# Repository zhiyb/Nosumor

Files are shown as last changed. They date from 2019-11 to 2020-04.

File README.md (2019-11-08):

# USB Mix

Design a small USB keyboard for playing [osu!](https://osu.ppy.sh/): [Blog posts](https://zhiyb.wordpress.com/category/cc/embedded/nosumor/)

In addition to mandatory keyboard functionalities, USB audio and Micro SD support are also added. So it's now called USB Mix.

The PCB layout was made compatible with [the original Nosumor v3 casing](http://noodlefighter.com/工作日志/log_nono/), which sells on [the official osu! store](https://osu.ppy.sh/store/product/20).

However, as a hobby project for learning USB framework and achieving high performance, the parts used in this design are probably unnecessarily expensive.

## Features

- USB 2.0 high-speed connection with 8kHz polling rate
- 5 switches (2x Cherry MX switches & 3x tactile switches)
- RGB lighting!
- Audio output through headphone jack using USB audio class 2
- Micro SD card reader
- Application for dynamic reconfiguration and firmware upgrade

### Planned features

- Audio input (MIC) through headphone jack
- MPU-9250 9-axis motion sensor
- ADC waveform capture
- DAC waveform generation

## PCB features

- 50×50 (mm) board area
- 2 mechanical keyboard switches (Cherry MX RGB compatible) and 3 tactile buttons
- Keycap and bottom-side RGB lighting
- STM32F722RE Cortex-M7 high performance MCU @216MHz
- USB 2.0 high-speed PHY USB3370
- 3.5mm audio jack with TLV320AIC3110 audio codec
- InvenSense MPU-9250 9-axis motion sensor
- On-board FT2232D connected to UART & JTAG for debugging
- Test points for 2xADC & 1xDAC
- Extension UART port with 3.3V power

Gerber files for PCB manufacturer Seeed Studio provided.

## Estimated costs

Configuration | Cost
---|---
Basic keyboard | £20
With audio and Micro SD slot | £30
Also with debugging USB port | £38

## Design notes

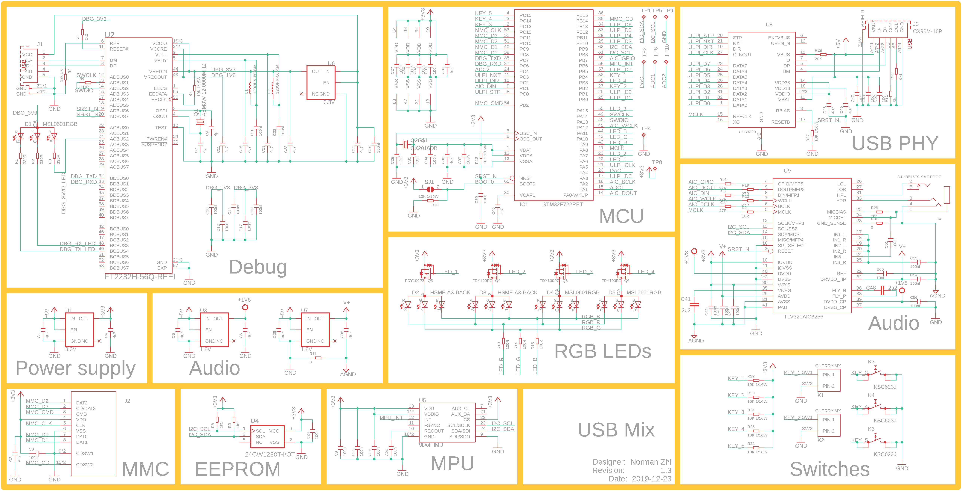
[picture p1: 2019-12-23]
images/schematic.png

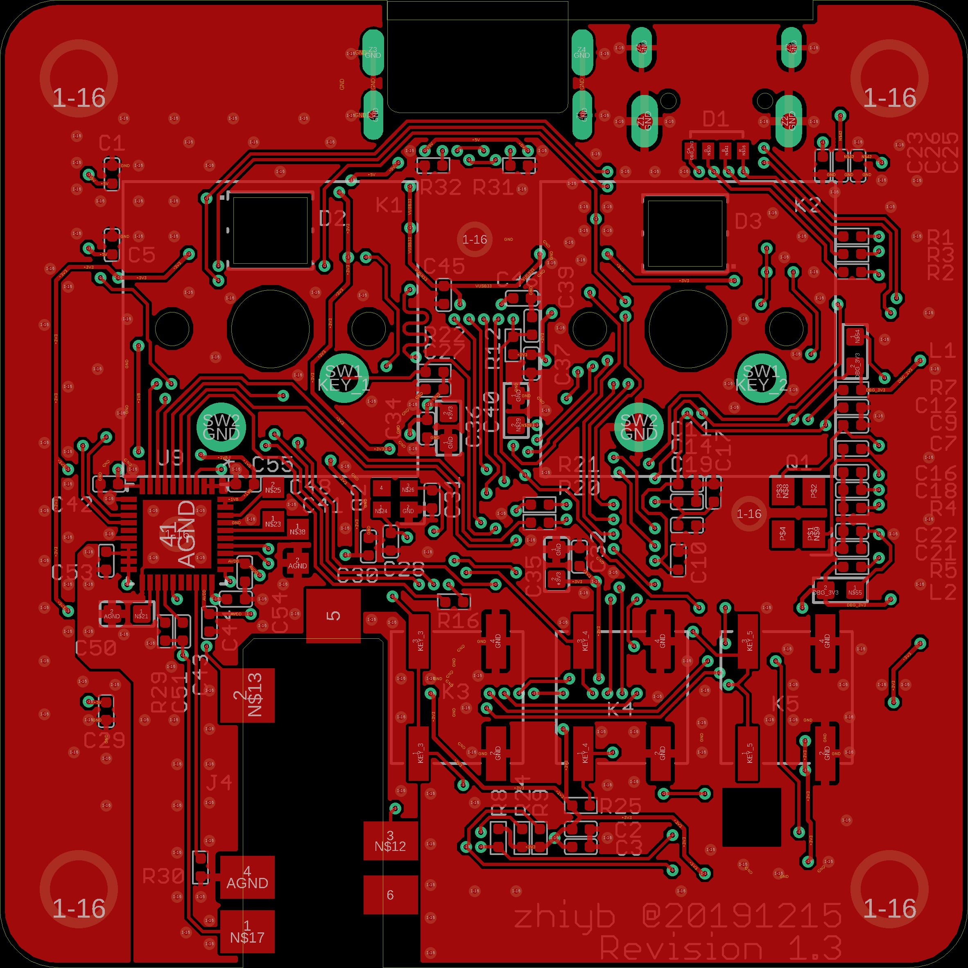
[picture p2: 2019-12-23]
images/top.png

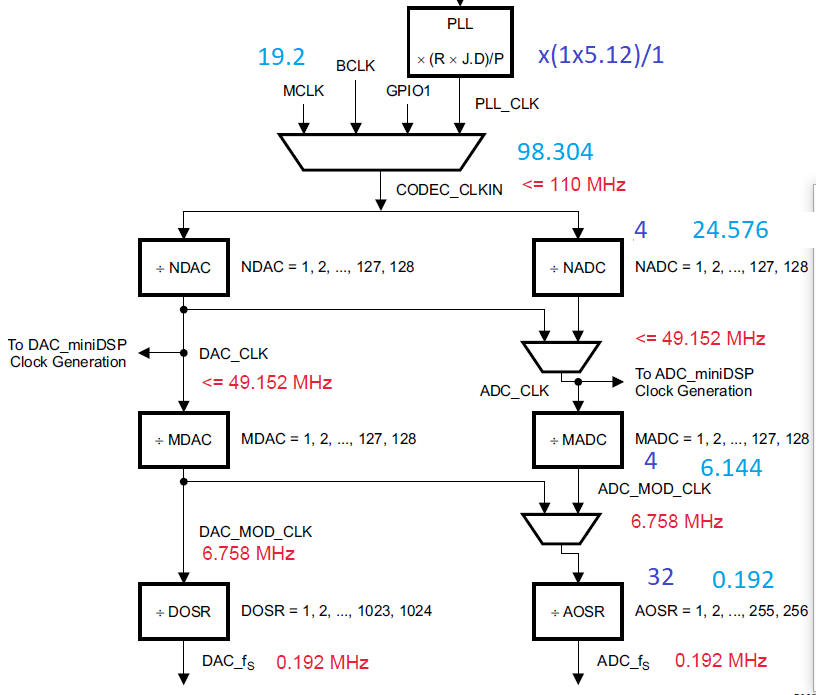
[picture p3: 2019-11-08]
images/codec.png

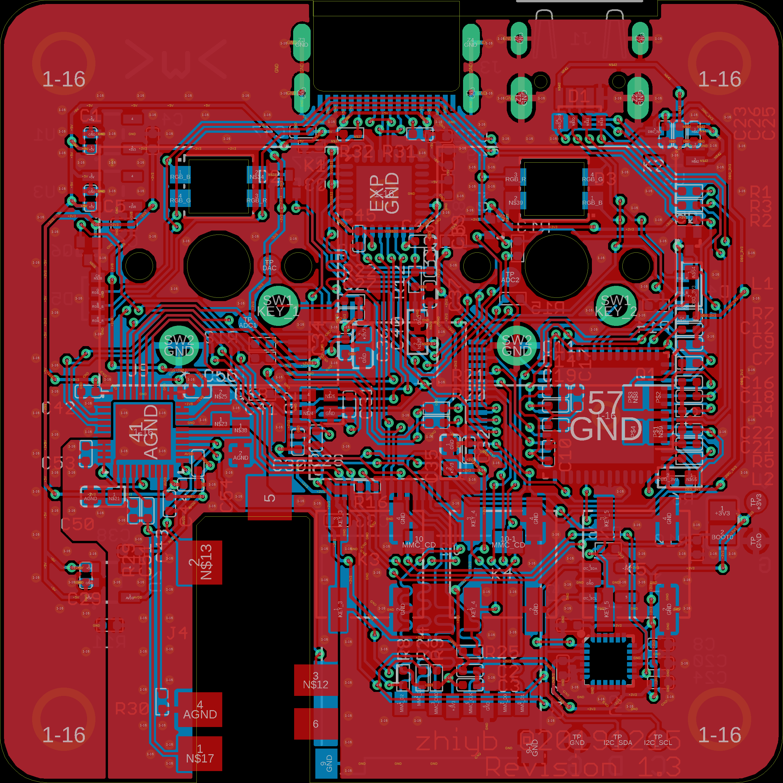
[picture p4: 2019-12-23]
images/both.png

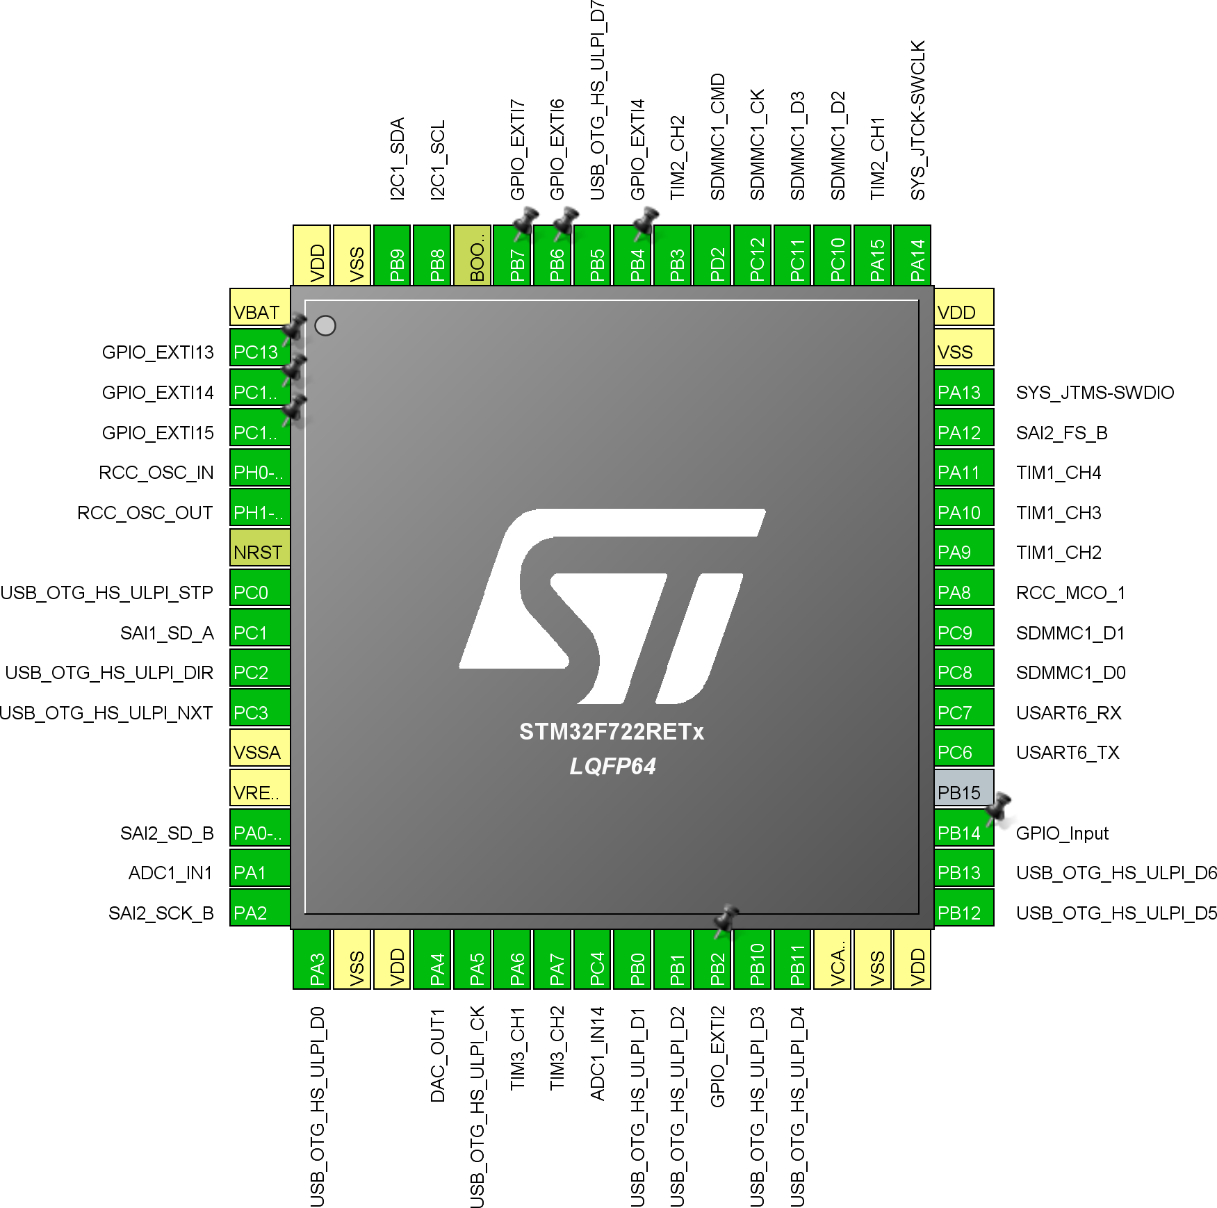
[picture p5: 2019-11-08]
images/chip.png

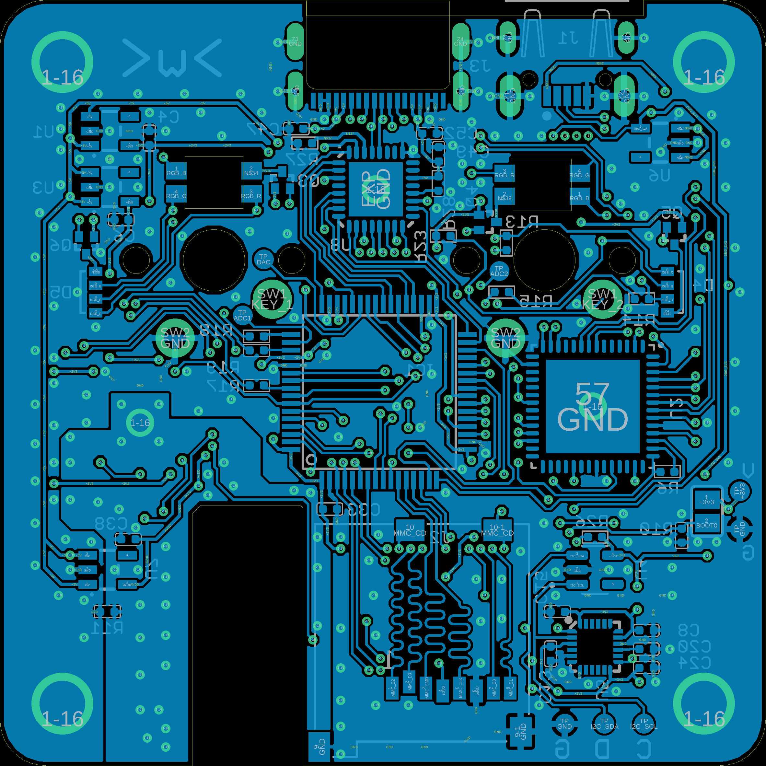
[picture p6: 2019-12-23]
images/bottom.png

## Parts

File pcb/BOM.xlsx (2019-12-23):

Section | Type | Value | Designator | Part # | Quantity | Unit Price | Link
Audio | Capacitor | 100n | C42, C43, C44, C51, C53, C54, C55 | CC0402KRX7R7BB104 | 7 | £0.009 | https://www.mouser.co.uk/ProductDetail/603-CC402KRX7R7BB104
Audio | Capacitor | 10u | C50 | GRM188R60J106ME47D | 1 | £0.218 | https://www.mouser.co.uk/productdetail/81-grm188r60j106me47
Audio | Capacitor | 2u2 | C41, C48 | C1608X7R1A225K080AC | 2 | £0.148 | https://www.mouser.co.uk/ProductDetail/810-C1608X7R1A225K
Audio | Capacitor | 4u7 | C5, C6, C29, C38 | GRM155R61A475MEAAD | 4 | £0.066 | https://www.mouser.co.uk/ProductDetail/81-GRM155R61A475MEAD
Audio | Connector | 3.5mm Jack | J4 | SJ-43515TS-SMT-TR | 1 | £0.816 | https://www.mouser.co.uk/ProductDetail/490-SJ43515TS-SMT-TR
Audio | IC | AP2112K-1.8V | U3, U7 | AP2112K-1.8TRG1 | 2 | £0.250 | https://www.mouser.co.uk/ProductDetail/621-AP2112K-1.8TRG1
Audio | IC | TLV320AIC3256 | U9 | TLV320AIC3256IRSBT | 1 | £8.530 | https://www.mouser.co.uk/ProductDetail/595-V320AIC3256IRSBT
Audio | Resistor | 0R | R11, R30 | RC0402FR-070RL | 2 | £0.003 | https://www.mouser.co.uk/ProductDetail/603-RC0402FR-070RL
Audio | Resistor | 10R | R21 | RC0402FR-0710RL | 1 | £0.004 | https://www.mouser.co.uk/ProductDetail/Yageo/RC0402FR-0710RL
Audio | Resistor | 27R | R16, R17, R18, R19, R20 | RC0402FR-0727RL | 5 | £0.003 | https://www.mouser.co.uk/ProductDetail/603-RC0402FR-0727RL
Audio | Resistor | 2k7 | R29 | RC0402FR-072K7L | 1 | £0.003 | https://www.mouser.co.uk/ProductDetail/603-RC0402FR-072K7L
Basic | Capacitor | 100n | C27, C30, C32, C33, C34, C37, C39, C49, C52 | CC0402KRX7R7BB104 | 9 | £0.009 | https://www.mouser.co.uk/ProductDetail/603-CC402KRX7R7BB104
Basic | Capacitor | 12p | C28, C31 | GRM1555C1H120JA01D | 2 | £0.031 | https://www.mouser.co.uk/productdetail/81-grm1555c1h120ja1d
Basic | Capacitor | 4u7 | C1, C4, C35, C36, C40, C45, C46, C47 | GRM155R61A475MEAAD | 8 | £0.066 | https://www.mouser.co.uk/ProductDetail/81-GRM155R61A475MEAD
Basic | Connector | USB Type-C | J3 | CX90M-16P | 1 | £1.750 | https://www.mouser.co.uk/ProductDetail/798-CX90M-16P
Basic | Crystal | 19.2M | Q2 | CX2016DB19200H0FLJC2 | 1 | £0.461 | https://www.mouser.co.uk/ProductDetail/581-CX2016DB19200HLJ
Basic | IC | AP2112K-3.3V | U1 | AP2112K-3.3TRG1 | 1 | £0.250 | https://www.mouser.co.uk/ProductDetail/621-AP2112K-3.3TRG1
Basic | IC | STM32F722 | IC1 | STM32F722RET6 | 1 | £7.900 | https://www.mouser.co.uk/ProductDetail/511-STM32F722RET6
Basic | IC | USB3370B | U8 | USB3370B-EZK-TR | 1 | £1.210 | https://www.mouser.co.uk/productdetail/886-usb3370b-ezk-tr
Basic | LED | RGB | D2, D3 | ASMB-MTB1-0A3A2 | 2 | £0.274 | https://uk.rs-online.com/web/p/visible-leds/8305079/
Basic | LED | RGB Sideway | D4, D5 | MSL0601RGBU1 | 2 | £0.673 | https://www.mouser.co.uk/ProductDetail/755-MSL0601RGBU1
Basic | MOSFET | P-Channel | Q3, Q4, Q5, Q6 | FDY100PZ | 4 | £0.230 | https://www.mouser.co.uk/ProductDetail/512-FDY100PZ
Basic | Resistor | 100R | R13, R14, R15 | RC0402FR-07100RL | 3 | £0.003 | https://www.mouser.co.uk/ProductDetail/603-RC0402FR-07100RL
Basic | Resistor | 10k | R10, R12, R22, R23, R24, R25, R26, R27 | RC0402FR-0710KL | 8 | £0.003 | https://www.mouser.co.uk/productdetail/603-rc0402fr-0710kl
Basic | Resistor | 20k | R28 | RC0402FR-0720KL | 1 | £0.003 | https://www.mouser.co.uk/productdetail/603-rc0402fr-0720kl
Basic | Resistor | 2k2 | R8, R9 | RC0402FR-072K2L | 2 | £0.003 | https://www.mouser.co.uk/productdetail/603-rc0402fr-072k2l
Basic | Resistor | 5k1 | R31, R32 | RC0402FR-075K1L | 2 | £0.003 | https://www.mouser.co.uk/ProductDetail/603-RC0402FR-075K1L
Basic | Switch | Cherry-MX | K1, K2 |  | 2 | £1.000
Basic | Switch | Tactile | K3, K4, K5 | KSC623JLFG | 3 | £0.722 | https://www.mouser.co.uk/ProductDetail/611-KSC623JLFG
Debug | Capacitor | 100n | C10, C12, C14, C17, C18, C19, C22, C26 | CC0402KRX7R7BB104 | 8 | £0.009 | https://www.mouser.co.uk/ProductDetail/603-CC402KRX7R7BB104
Debug | Capacitor | 4p | C7, C9 | GJM1555C1H4R0BB01D | 2 | £0.100 | https://www.mouser.co.uk/ProductDetail/81-GJM1555C1H4R0BB01
Debug | Capacitor | 4u7 | C11, C16, C21, C23, C25 | GRM155R61A475MEAAD | 5 | £0.066 | https://www.mouser.co.uk/ProductDetail/81-GRM155R61A475MEAD
Debug | Connector | USB Micro-B | J1 | 629105150521 | 1 | £1.650 | https://www.mouser.co.uk/ProductDetail/710-629105150521
Debug | Crystal | 12M | Q1 | ABM8W-12.0000MHZ-4-D1X-T3 | 1 | £0.587 | https://www.mouser.co.uk/ProductDetail/815-8W12-4D1XT
Debug | IC | AP2112K-3.3V | U6 | AP2112K-3.3TRG1 | 1 | £0.250 | https://www.mouser.co.uk/ProductDetail/621-AP2112K-3.3TRG1
Debug | IC | FT2232H | U2 | FT2232H-56Q-TRAY | 1 | £4.430 | https://www.mouser.co.uk/ProductDetail/895-FT2232H-56Q-TRAY
Debug | Inductor | 120R/500mA | L1, L2 | BLM18AG121BH1D | 2 | £0.033 | https://www.mouser.co.uk/ProductDetail/81-BLM18AG121BH1D
Debug | LED | RGB Sideway | D1 | MSL0601RGBU1 | 1 | £0.673 | https://www.mouser.co.uk/ProductDetail/755-MSL0601RGBU1
Debug | Resistor | 10k | R7 | RC0402FR-0710KL | 1 | £0.003 | https://www.mouser.co.uk/productdetail/603-rc0402fr-0710kl
Debug | Resistor | 12k 1% | R4 | RC0402FR-1312KL | 1 | £0.003 | https://www.mouser.co.uk/ProductDetail/603-RC0402FR-1312KL
Debug | Resistor | 2k2 | R5 | RC0402FR-072K2L | 1 | £0.003 | https://www.mouser.co.uk/productdetail/603-rc0402fr-072k2l
Debug | Resistor | 330R | R1, R2, R3, R6 | RC0402FR-07330RL | 4 | £0.003 | https://www.mouser.co.uk/productdetail/603-rc0402fr-07330rl
EEPROM | Capacitor | 100n | C24 | CC0402KRX7R7BB104 | 1 | £0.009 | https://www.mouser.co.uk/ProductDetail/603-CC402KRX7R7BB104
EEPROM | IC | 24CW1280T | U4 | 24CW1280T-I/OT | 1 | £0.351 | https://www.mouser.co.uk/ProductDetail/579-24CW1280T-I-OT
MMC | Capacitor | 100n | C3 | CC0402KRX7R7BB104 | 1 | £0.009 | https://www.mouser.co.uk/ProductDetail/603-CC402KRX7R7BB104
MMC | Capacitor | 4u7 | C2 | GRM155R61A475MEAAD | 1 | £0.066 | https://www.mouser.co.uk/ProductDetail/81-GRM155R61A475MEAD
MMC | Connector | Micro SD | J2 | 693071010811 | 1 | £2.320 | https://www.mouser.co.uk/ProductDetail/710-693071010811
MPU | Capacitor | 100n | C8, C13, C15, C20 | CC0402KRX7R7BB104 | 4 | £0.009 | https://www.mouser.co.uk/ProductDetail/603-CC402KRX7R7BB104
MPU | IC | MPU9250 | U5 | MPU-9250 | 1 | £7.130
Total |  |  |  |  | 119 | £48.185

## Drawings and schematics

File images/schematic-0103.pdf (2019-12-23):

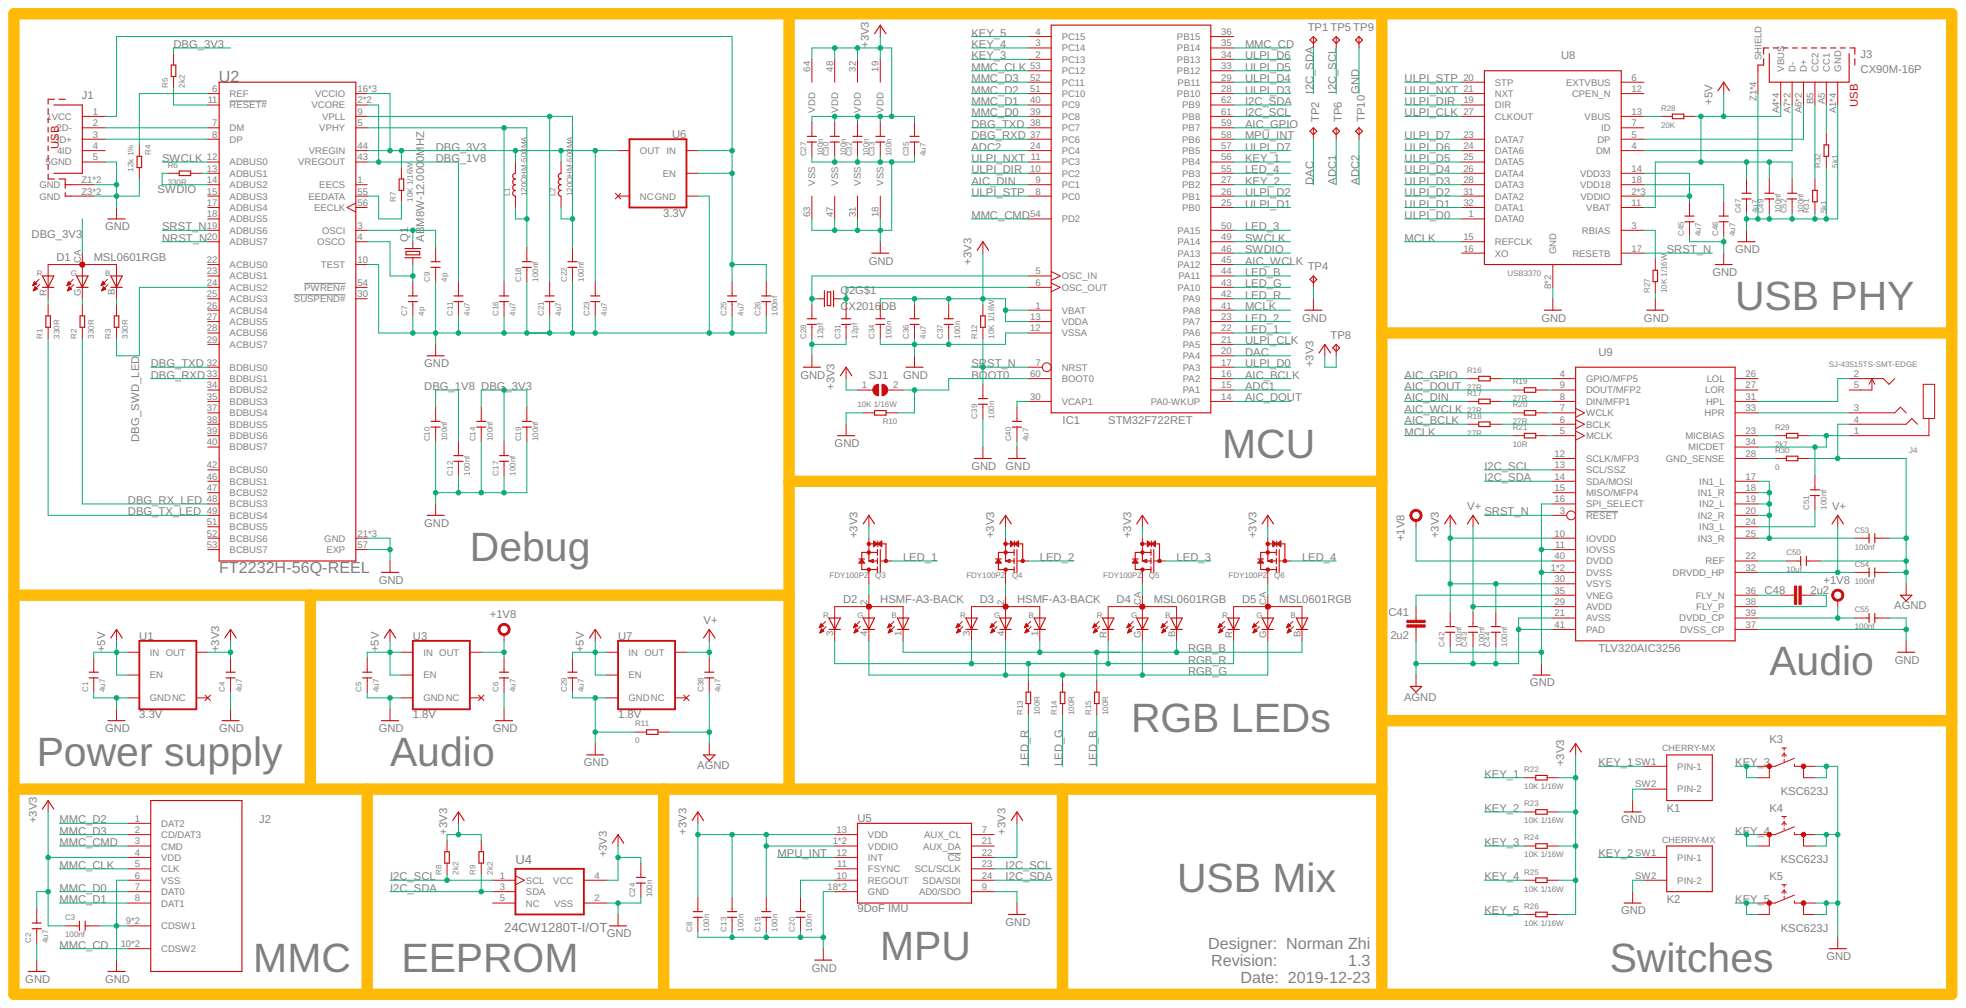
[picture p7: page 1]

IN GND OUT EN

21 | 39
41 | 37 DVDD_CP

RGB_R
RGB_G

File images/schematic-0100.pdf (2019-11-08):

# Switches

# Power supply

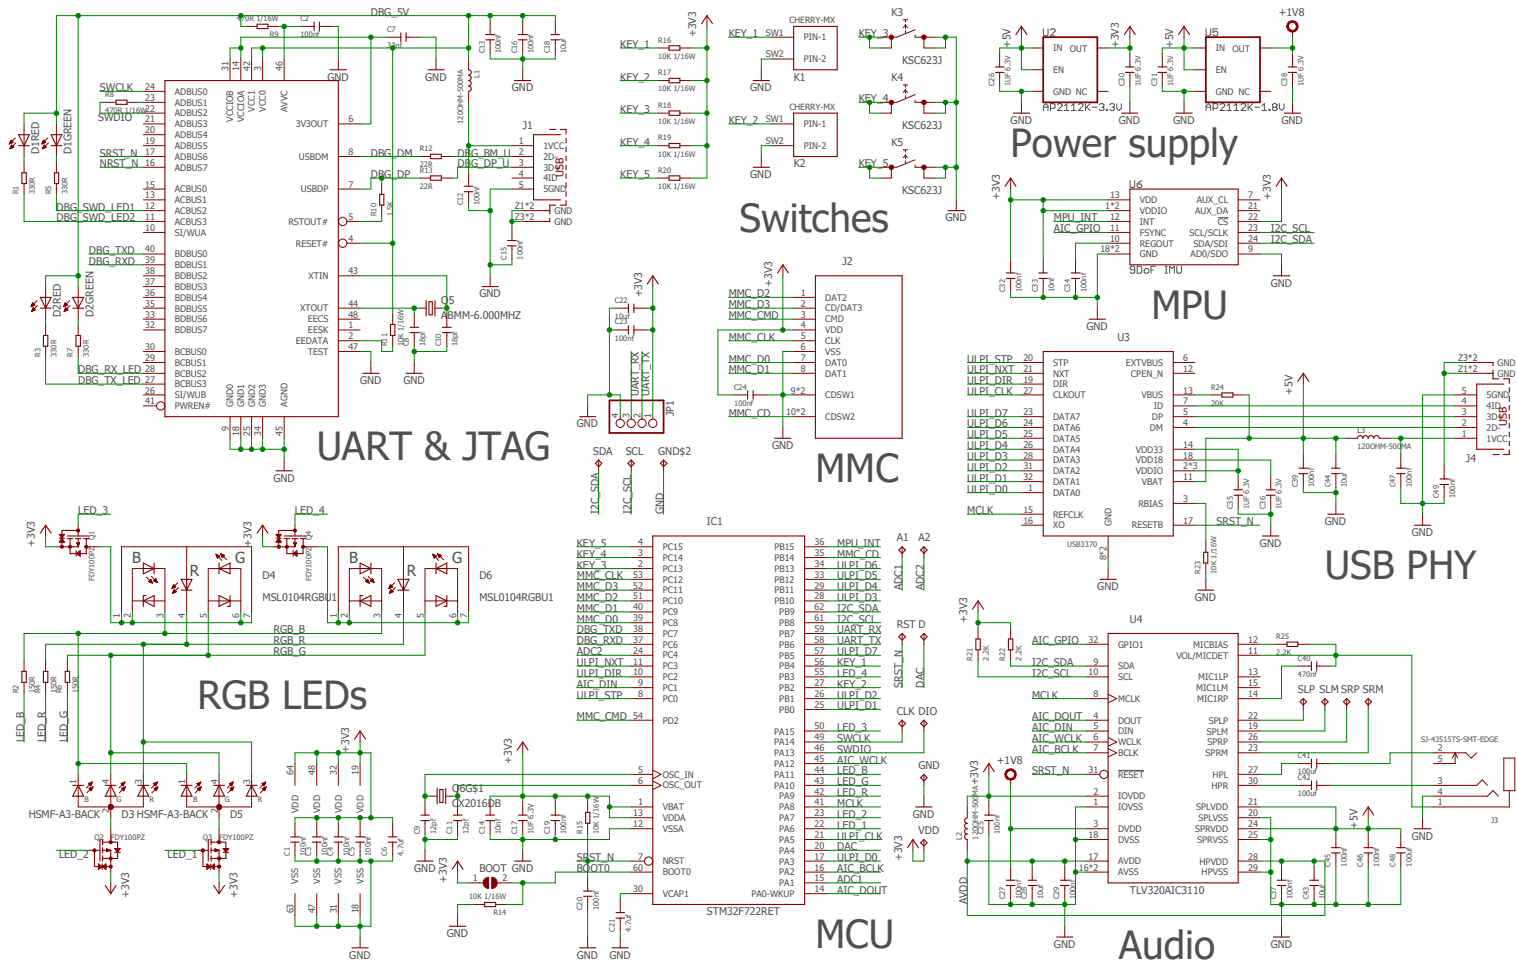
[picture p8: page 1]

SDA SCL GND$2 GND

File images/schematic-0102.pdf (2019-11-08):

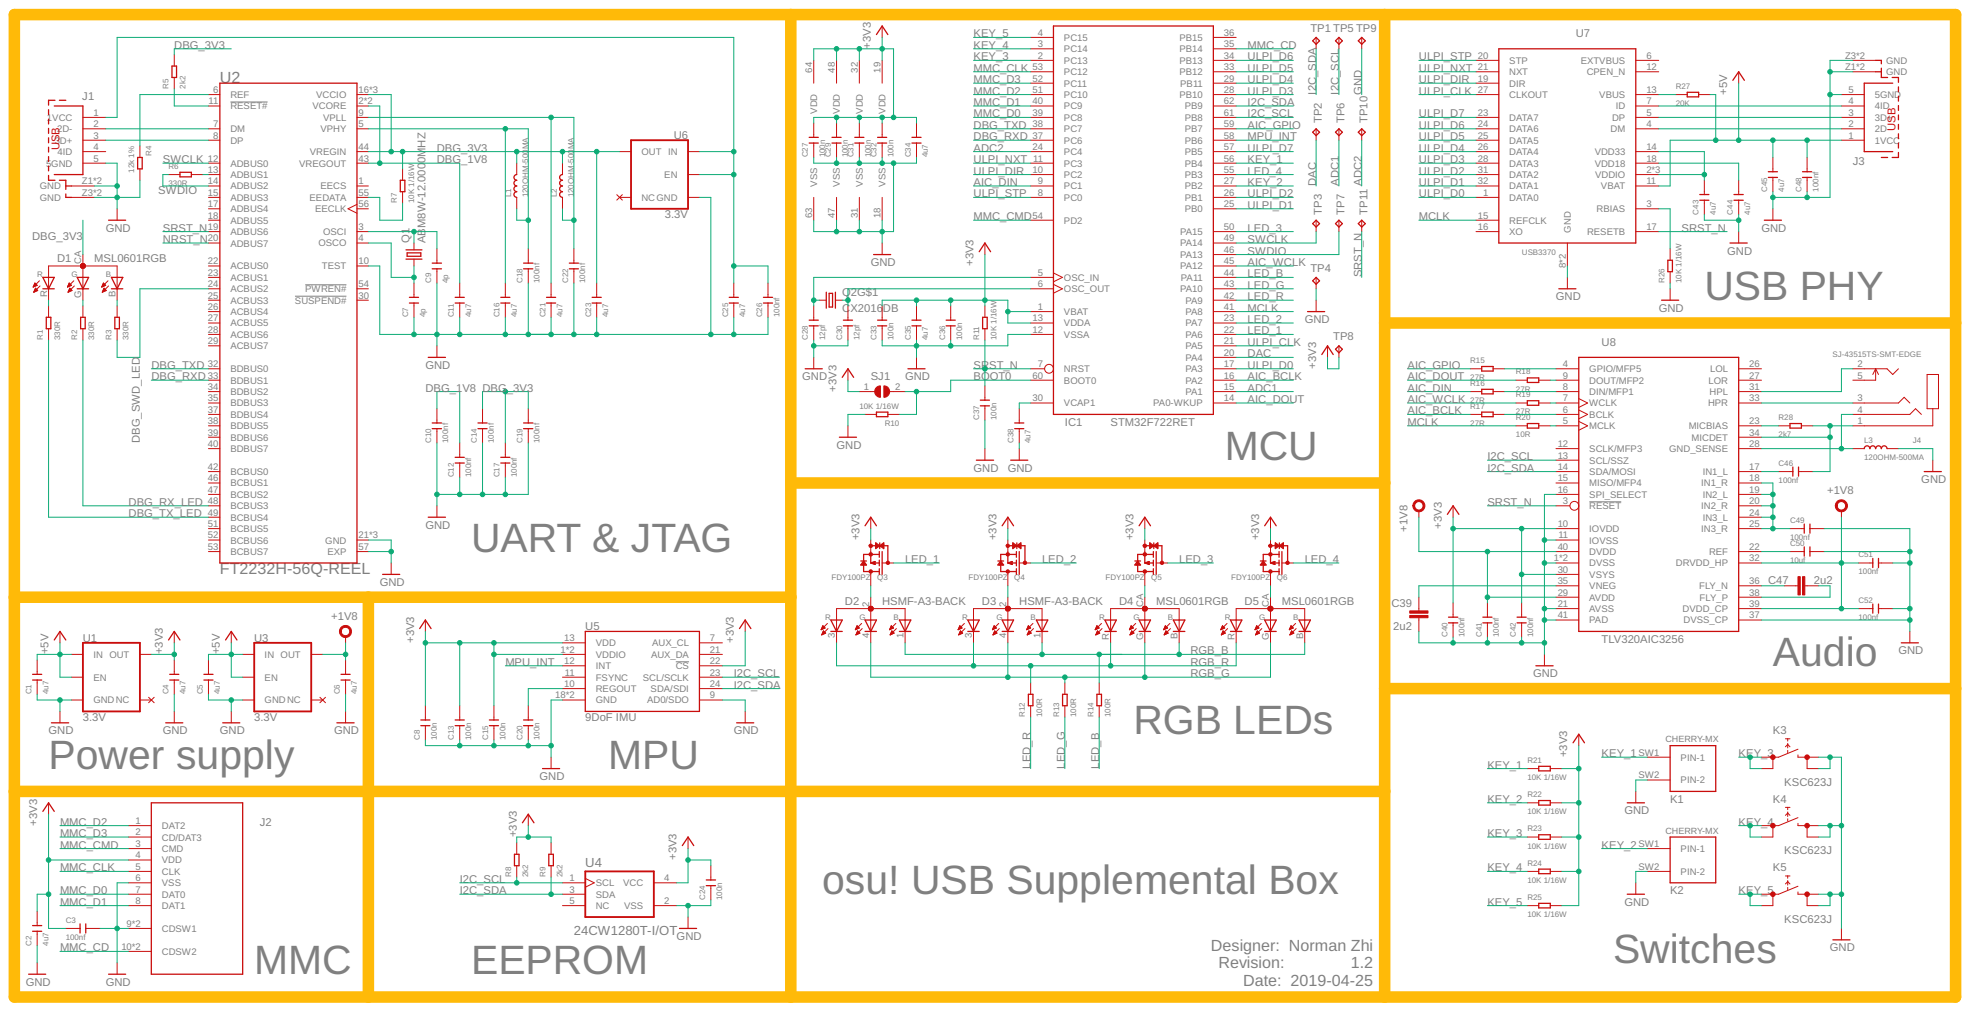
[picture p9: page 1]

IN GND OUT EN

osu! USB Supplemental Box

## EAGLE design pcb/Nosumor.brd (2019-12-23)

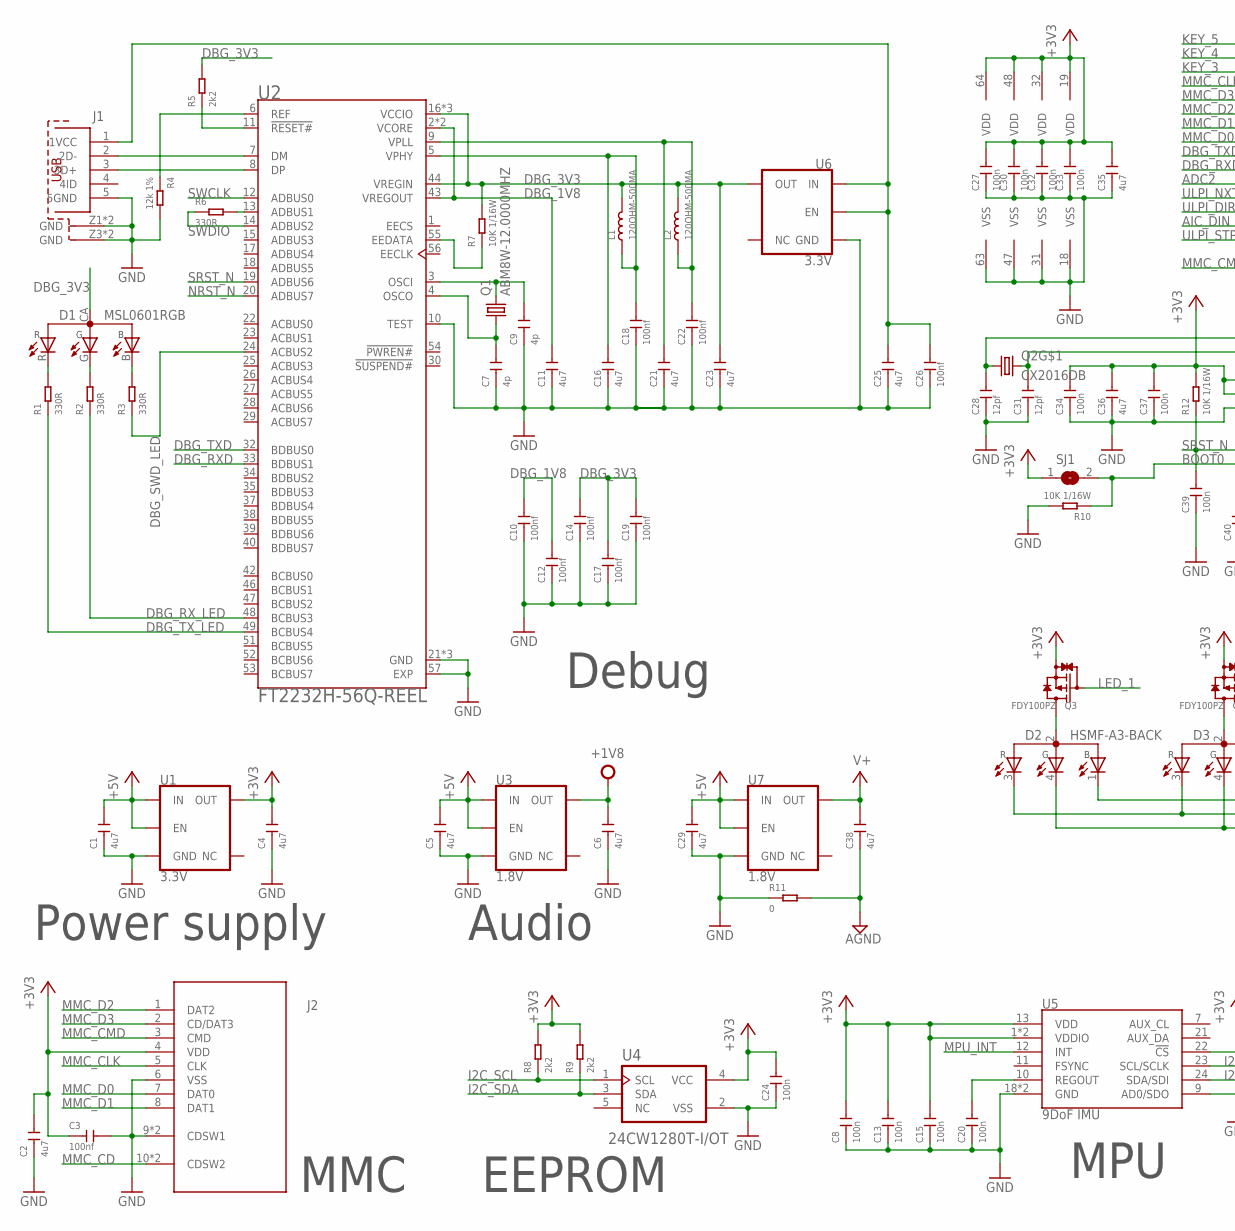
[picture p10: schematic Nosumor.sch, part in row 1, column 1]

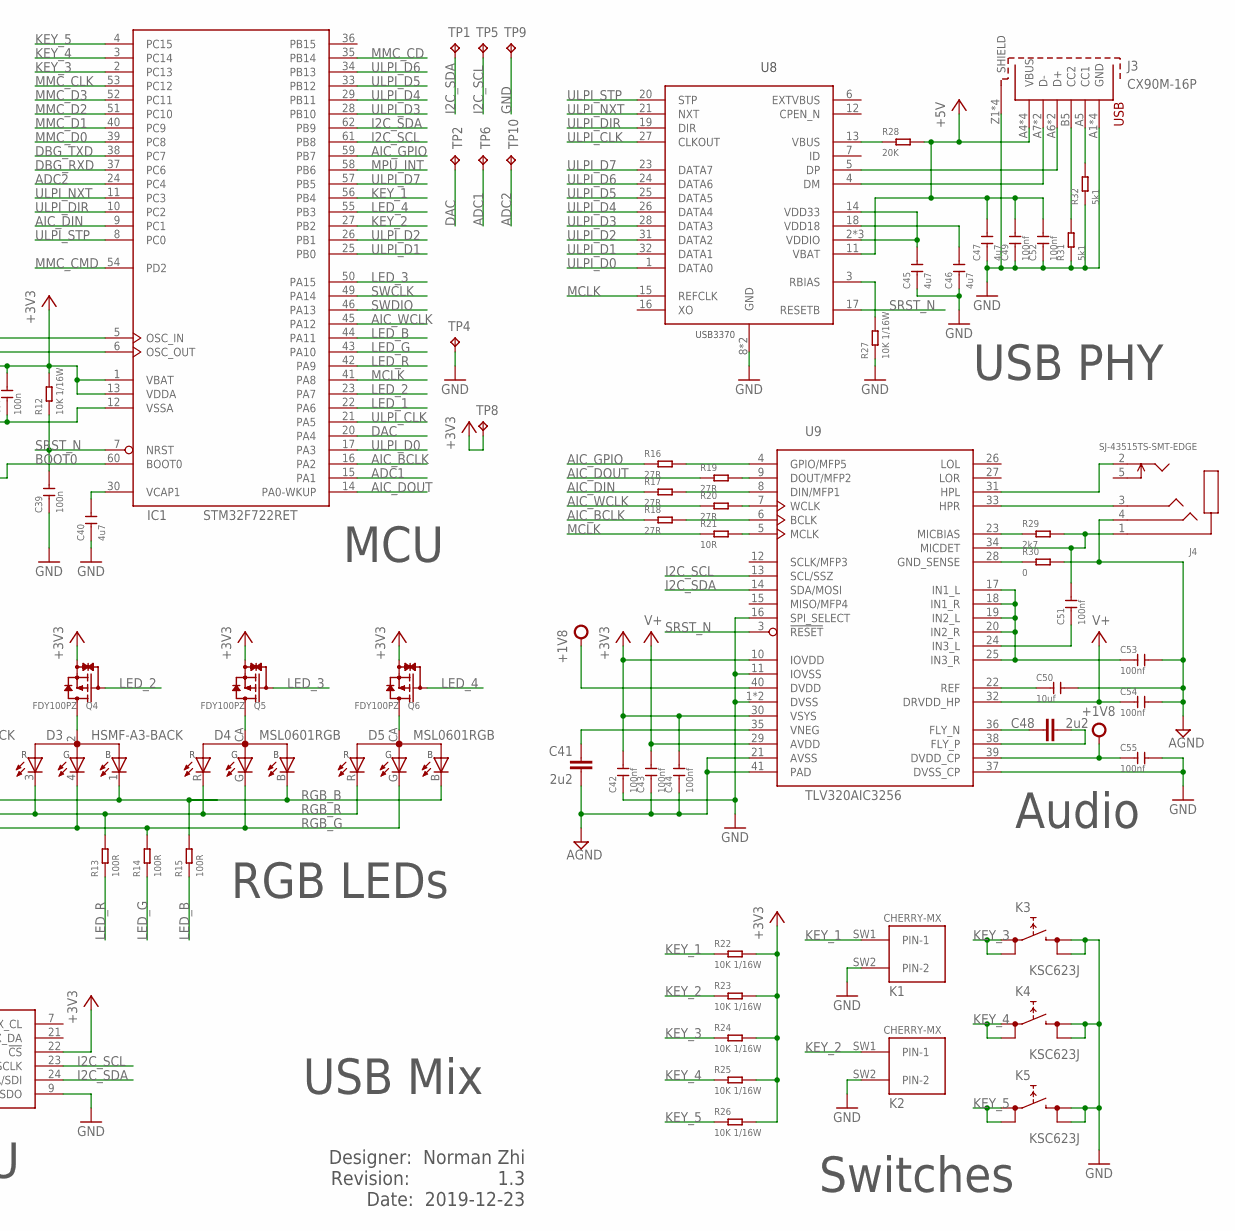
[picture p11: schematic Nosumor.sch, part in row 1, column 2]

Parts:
C1, C2, C4, C5, C6, C11, C16, C21, C23, C25, C29, C38, C45, C46, C47: 4u7; C0402
C3, C10, C12, C14, C17, C18, C19, C22, C26, C42, C43, C44, C49, C51, C52, C53, C54, C55: 100nf; C0402
C7, C9: 4p; C0402
C8, C13, C15, C20, C24, C27, C30, C32, C33, C34, C37, C39: 100n; C0402
C28, C31: 12pf; C0402
C35, C36, C40: 4u7; C0603
C41, C48: 2u2; C0603K
C50: 10uf; C0603
D1, D4, D5: MSL0601RGB; 1105
D2, D3: HSMF-A3-BACK
IC1: STM32F722RET; LQFP64
J1: 629105150521
J2: 693071010811
J3: CX90M-16P
J4: SJ-43515TS-SMT-EDGE; SJ-4351*-SMT-MIRRORED-EDGE
K1, K2: CHERRY-MX
K3, K4, K5: KSC623J; KSC-J
L1, L2: 120OHM-500MA; L0603
Q1: ABM8W-12.0000MHZ; ABM8W
Q2: CX2016DB
Q3, Q4, Q5, Q6: FDY100PZ; SC-89
R1, R2, R3, R6: 330R; R0402
R4: 12k 1%; R0402
R5, R8, R9: 2k2; R0402
R7, R10, R12, R22, R23, R24, R25, R26, R27: 10K 1/16W; R0402
R11, R30: 0; R0402
R13, R14, R15: 100R; R0402
R16, R17, R18, R19, R20: 27R; R0402
R21: 10R; R0402
R28: 20K; R0402
R29: 2k7; R0402
R31, R32: 5k1; R0402
SJ1: SJ
TP1, TP2, TP4, TP5, TP6, TP8, TP9, TP10: TPB1,27; B1,27
U1, U6: 3.3V; SOT23-5
U2: FT2232H-56Q-REEL; QFN50P800X800X100-57N
U3, U7: 1.8V; SOT23-5
U4: 24CW1280T-I/OT; SOT95P280X145-5N
U5: 9DoF IMU; QFN24-3X3
U8: USB3370; QFN32
U9: TLV320AIC3256; QFN40P500X500X80-41N

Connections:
+1V8: C6.2, C55.1, U3.5 (OUT), U9.39 (DVDD_CP), U9.40 (DVDD)
+3V3: C2.2, C3.1, C4.2, C8.2, C13.2, C15.2, C24.2, C27.2, C30.2, C32.2, C33.2, C34.2, C35.2, C36.2, C37.2, C42.2, C44.2, IC1.1 (VBAT), IC1.13 (VDDA), IC1.19 (VDD), IC1.32 (VDD), IC1.48 (VDD), IC1.64 (VDD), J2.4 (VDD), Q3.3 (S), Q4.3 (S), Q5.3 (S), Q6.3 (S), R8.2, R9.2, R12.2, R22.2, R23.2, R24.2, R25.2, R26.2, SJ1.1, TP8.TP, U1.5 (OUT), U4.4 (VCC), U5.1 (VDDIO), U5.8 (VDDIO), U5.13 (VDD), U5.22 (!CS), U9.10 (IOVDD), U9.30 (VSYS)
+5V: C1.2, C5.2, C29.2, C47.2, C49.2, C52.2, J3.A4 (VBUS), J3.A9 (VBUS), J3.B4 (VBUS), J3.B9 (VBUS), R28.2, U1.1 (IN), U1.3 (EN), U3.1 (IN), U3.3 (EN), U7.1 (IN), U7.3 (EN), U8.11 (VBAT)
ADC1: IC1.15 (PA1), TP6.TP
ADC2: IC1.24 (PC4), TP10.TP
AGND: C38.1, C41.2, C43.1, C44.1, C50.2, C53.2, C54.2, J4.4, R11.2, R30.2, U9.21 (AVSS), U9.41 (PAD)
AIC_BCLK: IC1.16 (PA2), R18.1
AIC_BCLK_R: R18.2, U9.6 (BCLK)
AIC_DIN: IC1.9 (PC1), R17.1
AIC_DIN_R: R17.2, U9.8 (DIN/MFP1)
AIC_DOUT: IC1.14 (PA0-WKUP), R19.1
AIC_DOUT_R: R19.2, U9.9 (DOUT/MFP2)
AIC_GPIO: IC1.59 (PB7), R16.1
AIC_GPIO_R: R16.2, U9.4 (GPIO/MFP5)
AIC_MCLK_R: R21.2, U9.5 (MCLK)
AIC_WCLK: IC1.45 (PA12), R20.1
AIC_WCLK_R: R20.2, U9.7 (WCLK)
AVDD: C38.2, C43.2, C54.1, U7.5 (OUT), U9.29 (AVDD), U9.32 (DRVDD_HP)
BOOT0: IC1.60 (BOOT0), R10.1, SJ1.2
DAC: IC1.20 (PA4), TP2.TP
DBG_1V8: C10.2, C11.2, C12.2, U2.2 (VCORE), U2.31 (VCORE), U2.43 (VREGOUT)
DBG_3V3: C14.2, C17.2, C19.2, C23.2, D1.CA (A), L1.2, L2.2, R5.2, R7.2, U2.16 (VCCIO), U2.36 (VCCIO), U2.44 (VREGIN), U2.50 (VCCIO), U6.5 (OUT)
DBG_DM: J1.2 (2D-), U2.7 (DM)
DBG_DP: J1.3 (3D+), U2.8 (DP)
DBG_RXD: IC1.37 (PC6), U2.33 (BDBUS1)
DBG_RX_LED: R2.1, U2.48 (BCBUS3)
DBG_SWD_LED: R3.1, U2.24 (ACBUS2)
DBG_TXD: IC1.38 (PC7), U2.32 (BDBUS0)
DBG_TX_LED: R1.1, U2.49 (BCBUS4)
GND: C1.1, C2.1, C3.2, C4.1, C5.1, C6.1, C7.1, C8.1, C9.1, C10.1, C11.1, C12.1, C13.1, C14.1, C15.1, C16.1, C17.1, C18.1, C19.1, C20.1, C21.1, C22.1, C23.1, C24.1, C25.1, C26.1, C27.1, C28.1, C29.1, C30.1, C31.1, C32.1, C33.1, C34.1, C35.1, C36.1, C37.1, C39.1, C40.1, C42.1, C45.1, C46.1, C47.1, C49.1, C52.1, C55.2, IC1.12 (VSSA), IC1.18 (VSS), IC1.31 (VSS), IC1.47 (VSS), IC1.63 (VSS), J1.5 (5GND), J1.Z1 (GND), J1.Z2 (GND), J1.Z3 (GND), J1.Z4 (GND), J2.6 (VSS), J2.9 (CDSW1), J2.9-1 (CDSW1), J3.A1 (GND), J3.A12 (GND), J3.B1 (GND), J3.B12 (GND), J3.Z1 (SHIELD), J3.Z2 (SHIELD), J3.Z3 (SHIELD), J3.Z4 (SHIELD), K1.SW2 (PIN-2), K2.SW2 (PIN-2), K3.2, K3.4 (2), K4.2, K4.4 (2), K5.2, K5.4 (2), Q2.2 (GND), R4.2, R10.2, R11.1, R27.1, R31.1, R32.1, TP4.TP, TP9.TP, U1.2 (GND), U2.10 (TEST), U2.21 (GND), U2.41 (GND), U2.45 (GND), U2.57 (EXP), U3.2 (GND), U4.2 (VSS), U5.9 (AD0/SDO), U5.18 (GND), U5.20 (GND), U6.2 (GND), U7.2 (GND), U8.8 (GND), U8.EXP (GND), U9.1 (DVSS), U9.2 (DVSS), U9.11 (IOVSS), U9.16 (SPI_SELECT), U9.37 (DVSS_CP)
I2C_SCL: IC1.61 (PB8), R8.1, TP5.TP, U4.1 (SCL), U5.23 (SCL/SCLK), U9.13 (SCL/SSZ)
I2C_SDA: IC1.62 (PB9), R9.1, TP1.TP, U4.3 (SDA), U5.24 (SDA/SDI), U9.14 (SDA/MOSI)
KEY_1: IC1.56 (PB4), K1.SW1 (PIN-1), R22.1
KEY_2: IC1.27 (PB2), K2.SW1 (PIN-1), R23.1
KEY_3: IC1.2 (PC13), K3.1, K3.3 (1), R24.1
KEY_4: IC1.3 (PC14), K4.1, K4.3 (1), R25.1
KEY_5: IC1.4 (PC15), K5.1, K5.3 (1), R26.1
LED_1: IC1.22 (PA6), Q3.1 (G)
LED_2: IC1.23 (PA7), Q4.1 (G)
LED_3: IC1.50 (PA15), Q5.1 (G)
LED_4: IC1.55 (PB3), Q6.1 (G)
LED_B: IC1.44 (PA11), R15.1
LED_G: IC1.43 (PA10), R14.1
LED_R: IC1.42 (PA9), R13.1
MCLK: IC1.41 (PA8), R21.1, U8.15 (REFCLK)
MMC_CD: IC1.35 (PB14), J2.10 (CDSW2), J2.10-1 (CDSW2)
MMC_CLK: IC1.53 (PC12), J2.5 (CLK)
MMC_CMD: IC1.54 (PD2), J2.3 (CMD)
MMC_D0: IC1.39 (PC8), J2.7 (DAT0)
MMC_D1: IC1.40 (PC9), J2.8 (DAT1)
MMC_D2: IC1.51 (PC10), J2.1 (DAT2)
MMC_D3: IC1.52 (PC11), J2.2 (CD/DAT3)
MPU_INT: IC1.58 (PB6), U5.12 (INT)
unnamed: J3.A5 (CC1), R32.2
unnamed: J3.A7 (D-), J3.B7 (D-), U8.4 (DM)
unnamed: J3.A6 (D+), J3.B6 (D+), U8.5 (DP)
unnamed: J3.B5 (CC2), R31.2
unnamed: C9.2, Q1.P$3 (2), U2.3 (OSCI)
unnamed: C7.2, Q1.P$1 (1), U2.4 (OSCO)
unnamed: C51.1, U9.24 (IN3_L)
unnamed: D4.CA (A), Q5.2 (D)
unnamed: J4.3, U9.33 (HPR)
unnamed: J4.2, U9.31 (HPL)
unnamed: R7.1, U2.55 (EEDATA)
unnamed: D1.R (KR), R1.2
unnamed: C51.2, J4.1, R29.2, U9.34 (MICDET)
unnamed: R29.1, U9.23 (MICBIAS)
unnamed: R30.1, U9.28 (GND_SENSE)
unnamed: C53.1, U9.17 (IN1_L), U9.18 (IN1_R), U9.19 (IN2_L), U9.20 (IN2_R), U9.25 (IN3_R)
unnamed: C50.1, U9.22 (REF)
unnamed: C48.1, U9.36 (FLY_N)
unnamed: C28.2, IC1.5 (OSC_IN), Q2.1
unnamed: C48.2, U9.38 (FLY_P)
unnamed: C31.2, IC1.6 (OSC_OUT), Q2.3 (2)
unnamed: D5.CA (A), Q6.2 (D)
unnamed: C40.2, IC1.30 (VCAP1)
unnamed: D1.G (KG), R2.2
unnamed: R28.1, U8.13 (VBUS)
unnamed: D2.2 (A), Q3.2 (D)
unnamed: R27.2, U8.3 (RBIAS)
unnamed: C41.1, U9.35 (VNEG)
unnamed: D3.2 (A), Q4.2 (D)
unnamed: D1.B (KB), R3.2
unnamed: C25.2, C26.2, J1.1 (1VCC), U6.1 (IN), U6.3 (EN)
unnamed: C20.2, U5.10 (REGOUT)
unnamed: R4.1, U2.6 (REF)
unnamed: R5.1, U2.11 (!RESET#)
unnamed: C16.2, C18.2, L1.1, U2.5 (VPHY)
unnamed: C21.2, C22.2, L2.1, U2.9 (VPLL)
unnamed: R6.2, U2.13 (ADBUS1)
NRST_N: U2.20 (ADBUS7)
RGB_B: D2.1 (KB), D3.1 (KB), D4.B (KB), D5.B (KB), R15.2
RGB_G: D2.4 (KG), D3.4 (KG), D4.G (KG), D5.G (KG), R14.2
RGB_R: D2.3 (KR), D3.3 (KR), D4.R (KR), D5.R (KR), R13.2
SRST_N: C39.2, IC1.7 (NRST), R12.1, U2.19 (ADBUS6), U8.17 (RESETB), U9.3 (!RESET)
SWCLK: IC1.49 (PA14), U2.12 (ADBUS0)
SWDIO: IC1.46 (PA13), R6.1, U2.14 (ADBUS2)
ULPI_CLK: IC1.21 (PA5), U8.27 (CLKOUT)
ULPI_D0: IC1.17 (PA3), U8.1 (DATA0)
ULPI_D1: IC1.25 (PB0), U8.32 (DATA1)
ULPI_D2: IC1.26 (PB1), U8.31 (DATA2)
ULPI_D3: IC1.28 (PB10), U8.28 (DATA3)
ULPI_D4: IC1.29 (PB11), U8.26 (DATA4)
ULPI_D5: IC1.33 (PB12), U8.25 (DATA5)
ULPI_D6: IC1.34 (PB13), U8.24 (DATA6)
ULPI_D7: IC1.57 (PB5), U8.23 (DATA7)
ULPI_DIR: IC1.10 (PC2), U8.19 (DIR)
ULPI_NXT: IC1.11 (PC3), U8.21 (NXT)
ULPI_STP: IC1.8 (PC0), U8.20 (STP)
VUSB18: C46.2, U8.18 (VDD18)
VUSB33: C45.2, U8.2 (VDDIO), U8.14 (VDD33), U8.22 (VDDIO), U8.30 (VDDIO)

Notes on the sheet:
Debug
Switches
Power supply
MMC
USB PHY
Audio
MCU
RGB LEDs
MPU
EEPROM
Designer: Norman Zhi Revision: 1.3 Date: 2019-12-23
USB Mix

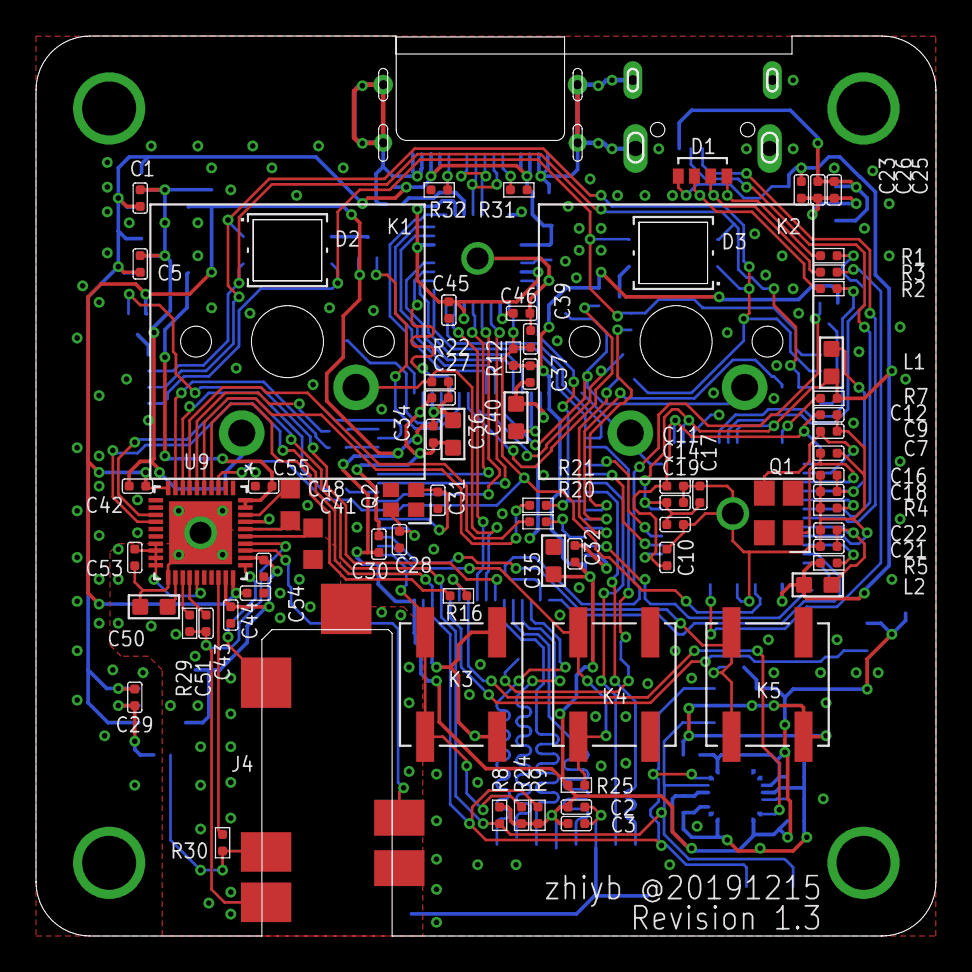
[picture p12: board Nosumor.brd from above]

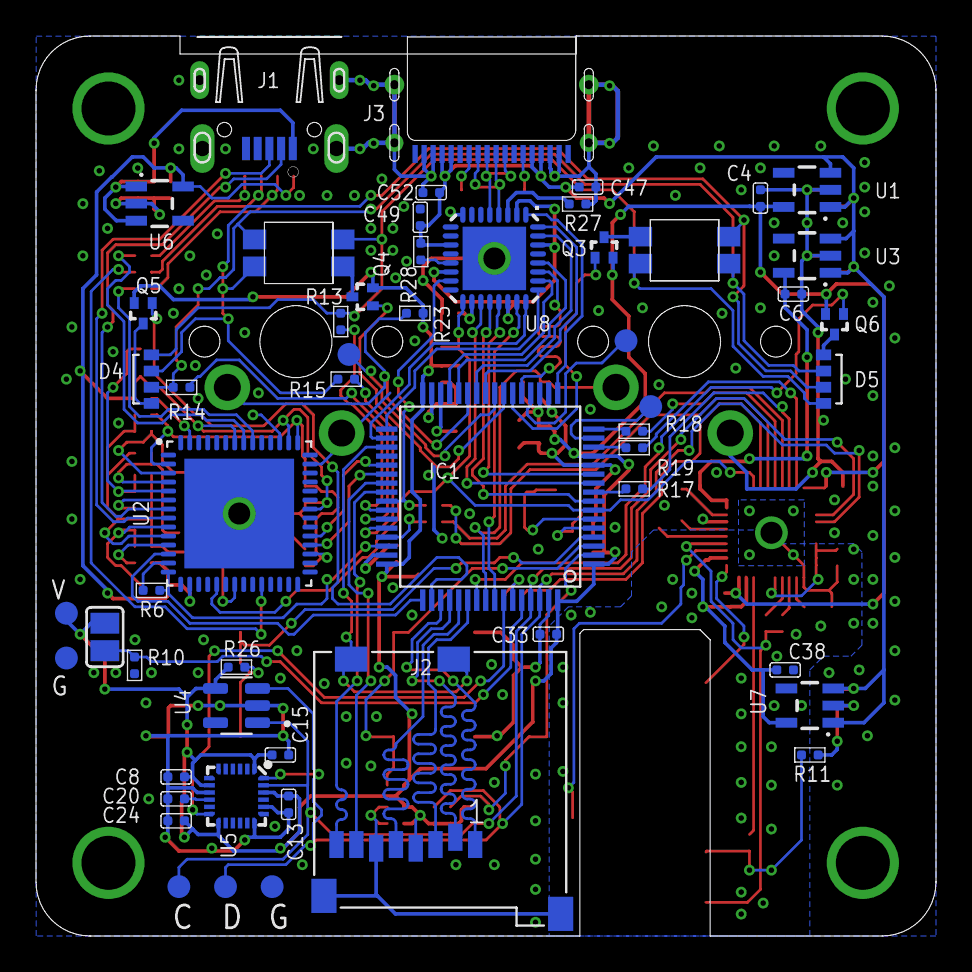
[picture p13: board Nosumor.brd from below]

Board: 2 copper layers, 50.0 x 50.0 mm, 128 parts (52 on the bottom side), 110 nets.

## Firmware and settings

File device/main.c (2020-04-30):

#include <stdio.h>
#include <debug.h>
#include <device.h>
#include <system/systick.h>
#include <system/system.h>
#include <peripheral/keyboard.h>
#include <usb/usb.h>

LIST(init, basic_handler_t);
LIST(idle, basic_handler_t);

static inline void init()
{
	printf(ESC_BOOT "%lu\tboot: " VARIANT " build @ " __DATE__ " " __TIME__ "\n", systick_cnt());
#if DEBUG >= 6
	extern void mem_test();
	mem_test();
#endif
	printf(ESC_INIT "%lu\tboot: Initialising peripherals\n", systick_cnt());
	LIST_ITERATE(init, basic_handler_t, p) (*p)();
	printf(ESC_INIT "%lu\tboot: Initialising USB systems\n", systick_cnt());
	usb_init();
#if DEBUG < 2
	printf(ESC_INIT "%lu\tboot: Soft connect USB port\n", systick_cnt());
	usb_connect(1);
#endif
	printf(ESC_INIT "%lu\tboot: Initialisation done\n", systick_cnt());
}

#if DEBUG >= 2
static void debug()
{
	static uint32_t _status = 0;
	uint32_t status = keyboard_status();

	if ((status & ~_status) & keyboard_masks[3]) {
		uint32_t connect = !usb_connected();
		usb_connect(connect);
	}

	_status = status;
}

IDLE_HANDLER(&debug);
#endif

int main()
{
	init();
	for (;;) {
		LIST_ITERATE(idle, basic_handler_t, p) (*p)();
		__WFI();
	}
	panic();
}

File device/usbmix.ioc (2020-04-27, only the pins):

PH0-OSC_IN.Signal=RCC_OSC_IN
Mcu.UserName=STM32F722RETx
PC10.Signal=SDMMC1_D2
PC12.Signal=SDMMC1_CK
PB11.Signal=USB_OTG_HS_ULPI_D4
PB13.Signal=USB_OTG_HS_ULPI_D6
PA12.Signal=SAI2_FS_B
PB6.Signal=GPXTI6
PC7.Signal=USART6_RX
PC3.Signal=USB_OTG_HS_ULPI_NXT
PB2.Signal=GPXTI2
PB7.Signal=GPXTI7
PA8.Signal=RCC_MCO_1
PB9.Signal=I2C1_SDA
PB1.Signal=USB_OTG_HS_ULPI_D2
PA6.Signal=S_TIM3_CH1
PA10.Signal=S_TIM1_CH3
PA15.Signal=S_TIM2_CH1_ETR
PB4.Signal=GPXTI4
PA3.Signal=USB_OTG_HS_ULPI_D0
PC11.Signal=SDMMC1_D3
PC13.Signal=GPXTI13
PC8.Signal=SDMMC1_D0
PC2.Signal=USB_OTG_HS_ULPI_DIR
PC4.Signal=ADCx_IN14
PC6.Signal=USART6_TX
PC0.Signal=USB_OTG_HS_ULPI_STP
PC14-OSC32_IN.Signal=GPXTI14
PA0-WKUP.Signal=SAI2_SD_B
PA13.Signal=SYS_JTMS-SWDIO
PA9.Signal=S_TIM1_CH2
PC15-OSC32_OUT.Signal=GPXTI15
PA1.Signal=ADCx_IN1
PB10.Signal=USB_OTG_HS_ULPI_D3
PB14.Signal=GPIO_Input
PA5.Signal=USB_OTG_HS_ULPI_CK
PH1-OSC_OUT.Signal=RCC_OSC_OUT
PA2.Signal=SAI2_SCK_B
PB3.Signal=S_TIM2_CH2
PA4.Signal=COMP_DAC1_group
PB5.Signal=USB_OTG_HS_ULPI_D7
PA11.Signal=S_TIM1_CH4
PA14.Signal=SYS_JTCK-SWCLK
PB8.Signal=I2C1_SCL
PC9.Signal=SDMMC1_D1
PD2.Signal=SDMMC1_CMD
PB0.Signal=USB_OTG_HS_ULPI_D1
PC1.Signal=SAI1_SD_A
PB12.Signal=USB_OTG_HS_ULPI_D5
PA7.Signal=S_TIM3_CH2

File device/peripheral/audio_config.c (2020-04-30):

#if 0

#include <usb/usb_desc.h>
#include <usb/audio2/usb_audio2_entities.h>
#include <usb/audio2/usb_audio2_desc.h>
#include <usb/audio2/usb_audio2_defs.h>
#include "audio.h"
#include "i2c.h"

static void *base;
#define I2C_ADDR	AUDIO_I2C_ADDR

#define SETCLR(src, bit, v)	if (v) (src) |= (bit); else (src) &= ~(bit)

// Entities
enum {
	IT_USB = 1,
	CS_PLL,
	CX_In,
	FU_DAC,
	FU_Headphone,
	FU_HeadphoneDriver,
	FU_Speaker,
	FU_SpeakerDriver,
	OT_Speaker,
	OT_Headphones,
};

// Configurations
typedef struct {
	int update;
	uint8_t dac;			// 0: 0x40
	struct {
		int8_t vol[2];		// 0: 0x41, 0x42
	} ch;
	struct {
		uint8_t atten[2];	// 1: 0x24, 0x25
		uint8_t gain[2];	// 1: 0x28, 0x29
	} hp;
	struct {
		uint8_t atten[2];	// 1: 0x26, 0x27
		uint8_t gain[2];	// 1: 0x2a, 0x2b
	} sp;
} cfg_t;

volatile cfg_t cfg SECTION(.dtcm);

void audio_init_reset(void *i2c)
{
	base = i2c;
	// Reset audio configurations
	i2c_write_reg(base, I2C_ADDR, 0x00, 0x00);
	i2c_write_reg(base, I2C_ADDR, 0x01, 0x01);
	// Wait for audio reset
	while (i2c_read_reg(base, I2C_ADDR, 0x01) & 0x01);
}

// Initial configuration
void audio_init_config()
{
	static const uint8_t cmd[] = {
#if HWVER >= 0x0101
		// ##### Power and Analog Configuration ###########################
		0x00, 0x01,		// Select Page 1
		0x01, 0x08,		// Disable weak AVDD to DVDD connection
		0x3a, 0x7c,		// Drive unused inputs to common mode
		0x02, 0x00,		// Enable Master Analog Power Control
		0x7b, 0x01,		// REF charging time = 40ms
		0x7c, 0x06,		// 8/8 CP Sizing (Setup A), Div = 6, 333kHz
		0x01, 0x0a,		// CP powered, source = int 8MHz OSC
		0x0a, 0x00,		// Full chip CM = 0.9V (Setup A)
		0x03, 0x00,		// PTM_P3, High Performance (Setup A)
		0x04, 0x00,		// PTM_P3, High Performance (Setup A)

		// ##### Clock and Interface Configuration ######################
		// --------------------------------------------------------------
		// AVDD = DVDD = 1.8 V
		// MCLK = 19.2 MHz (from MCO1)
		//
		// R = 1, J.D = 5.12, P = 1
		// D != 0: 512 kHz <= PLL_CLKIN / P <= 20 MHz
		// PLL_CLKIN = MCLK = 19.2 MHz
		// AVDD = 1.8 V, PLL mode = 0: 80 MHz <= PLL_CLK <= 132 MHz
		// PLL_CLK = PLL_CLKIN * R * J.D / P = 98.304 MHz
		//
		// NDAC = 2, MDAC = 8, DOSR = 32
		// DVDD >= 1.65 V, NDAC and NADC are even: CODEC_CLKIN <= 137 MHz
		// CODEC_CLKIN = PLL_CLK = 98.304 MHz
		// DVDD >= 1.65 V: DAC_CLK <= 55.296 MHz
		// DAC_CLK = CODEC_CLKIN / NDAC = 49.152 MHz
		// DVDD >= 1.65 V: DAC_MOD_CLK <= 6.758 MHz
		// DAC_MOD_CLK = DAC_CLK / MDAC = 6.144 MHz
		// DAC_fs <= 0.192 MHz
		// DAC_fs = DAC_MOD_CLK / DOSR = 192 kHz
		//
		// ADC same as DAC
		//
		// N = 4
		// BDIV_CLKIN = DAC_CLK = 49.152 MHz
		// BCLK = 2 * 32 * fs
		// BCLK = BDIV_CLKIN / N = 12.288 MHz
		//
		// 32-bit I2S, master mode
		// --------------------------------------------------------------
		0x00, 0x00,		// Select Page 0
		0x04, 0x03,		// MCLK => PLL => CODEC, low PLL clock range
		0x06, 0x05,		// PLL J = 5
		0x07, 1200u >> 8u,	// PLL D = .1200
		0x08, 1200u & 0xffu,	//
		0x05, 0x91,		// PLL enabled, P = 1, R = 1
		0x0b, 0x82,		// DAC NDAC = 2
		0x0c, 0x88,		// DAC MDAC = 8
		0x0d, 0,		// DAC DOSR = 32
		0x0e, 32,
		0x12, 0x84,		// ADC NADC = 2
		0x13, 0x84,		// ADC MADC = 8
		0x14, 32,		// ADC DOSR = 32
		0x1d, 0x00,		// No loopback, DAC_CLK => BCLK
		0x1e, 0x84,		// Enable BCLK N, N = 4

		0x1b, 0x3c,		// I2S, 32 bits, master, no high-Z
		//0x1d, 0x20,		// DIN-DOUT loopback
		//0x1d, 0x10,		// ADC-DAC loopback
		0x20, 0x00,		// Using primary interface inputs
		0x21, 0x00,		// Using primary interface outputs
		0x35, 0x12,		// Bus keeper disabled, DOUT from codec
		0x36, 0x02,		// DIN enabled

		// ####### Signal Processing Settings #############################
		0x00, 0x00,		// Select Page 0
		0x3c, 17,		// DAC using PRB_P17
		0x3d, 16,		// ADC using PRB_R16

		// ######## Output Channel Configuration ##########################
		0x00, 0x01,		// Select Page 1
		0x0c, 0x08,		// Route LDAC to HPL
		0x0d, 0x08,		// Route RDAC to HPR
		0x00, 0x00,		// Select Page 0
		0x40, 0x0c,		// DAC muted, independent volume
		0x3f, 0xd6,		// Power up LDAC/RDAC, no soft stepping
		0x00, 0x01,		// Select Page 1
		0x7d, 0x13,		// GCHP Mode, OC for all, HP Sizing (Setup A)
		0x10, 0x3a,		// Unmute HPL driver, -6dB Gain
		0x11, 0x3a,		// Unmute HPR driver, -6dB Gain
		0x09, 0x30,		// Power up HPL/HPR drivers
		// 0x02, xxxxx1xx # Wait for offset correction to finish
		//0x00, 0x00,		// Select Page 0
		//0x40, 0x00,		// Unmute LDAC/RDAC
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

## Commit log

2019-11-08 Initial common files
    [BOM.xlsx, Nosumor.brd, Nosumor.sch]
2019-11-09 Device code initial
2019-12-23 PCB revision 1.3 with USB Type-C, more datasheets
    [BOM.xlsx, Nosumor.brd, Nosumor.sch]
2020-04-26 USB device descriptor done
2020-04-27 device: USB HID keyboard initial
2020-04-28 device: Memory test for fun
2020-04-28 device: Use -O3 for memory test
2020-04-28 device: Memory test repeat 4 times
2020-04-30 device: UAC 2 initial

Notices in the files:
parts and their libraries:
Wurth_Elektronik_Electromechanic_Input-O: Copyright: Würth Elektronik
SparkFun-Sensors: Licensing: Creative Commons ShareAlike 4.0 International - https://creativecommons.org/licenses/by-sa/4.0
